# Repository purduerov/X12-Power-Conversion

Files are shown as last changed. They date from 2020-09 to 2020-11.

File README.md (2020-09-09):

# Readme for X12-Power-Conversion

Whenever you make a new part, download the datasheet and save it here _**and**_ with the part in the parts library

Always pull other people's changes before beginning to work
`git pull`

Be sure to push your changes after  working on them. Run:
1. `git add .` to add any files in this directory or a subdirectory
or `git add -u` to add any modified files
2. (Optional) `git clean -nX` to see what ignored files can be removed
	`git clean -fX` removes ignored files (Eagle backups)
3. `git commit -m "helpful commit message"` with a description of the work that you did
4. `git push` to push your work to github

Other helpful commands
* `git status` says information about modified and staged files
* `git log` shows the recent commits of the repository
* `git log filename.extension` show the recent commits for just that file
* `git checkout first-couple-letter-of-commit-id` lets you go back to a previous version
* `git checkout master` brings you back to the latest commit
* `git tag` lists the tags
* `git tag -a orderX -m "the version of the board placed for the X'th order"` tag a specific commit
* `git push --tags` needed to push tags to remote
* `git show orderX` show the commit log for the given tag
* `git checkout orderX` go back and interact with the files at the tagged commit

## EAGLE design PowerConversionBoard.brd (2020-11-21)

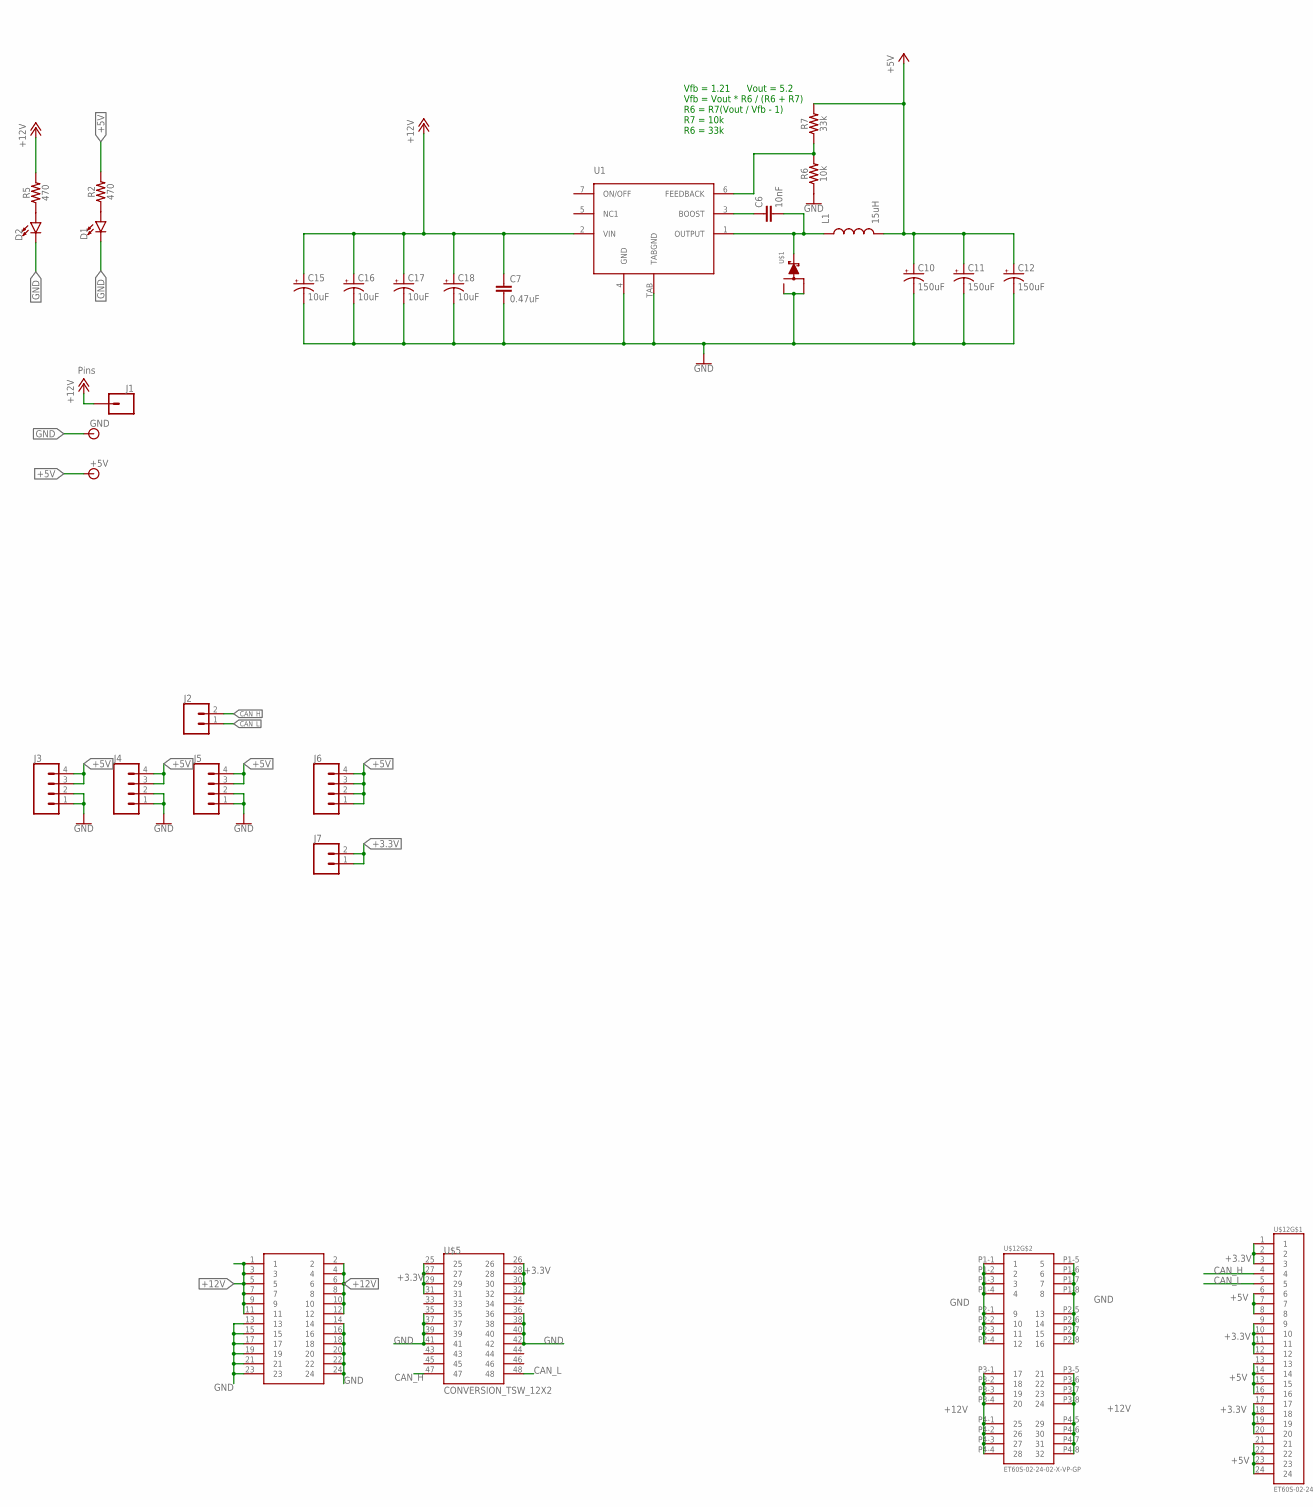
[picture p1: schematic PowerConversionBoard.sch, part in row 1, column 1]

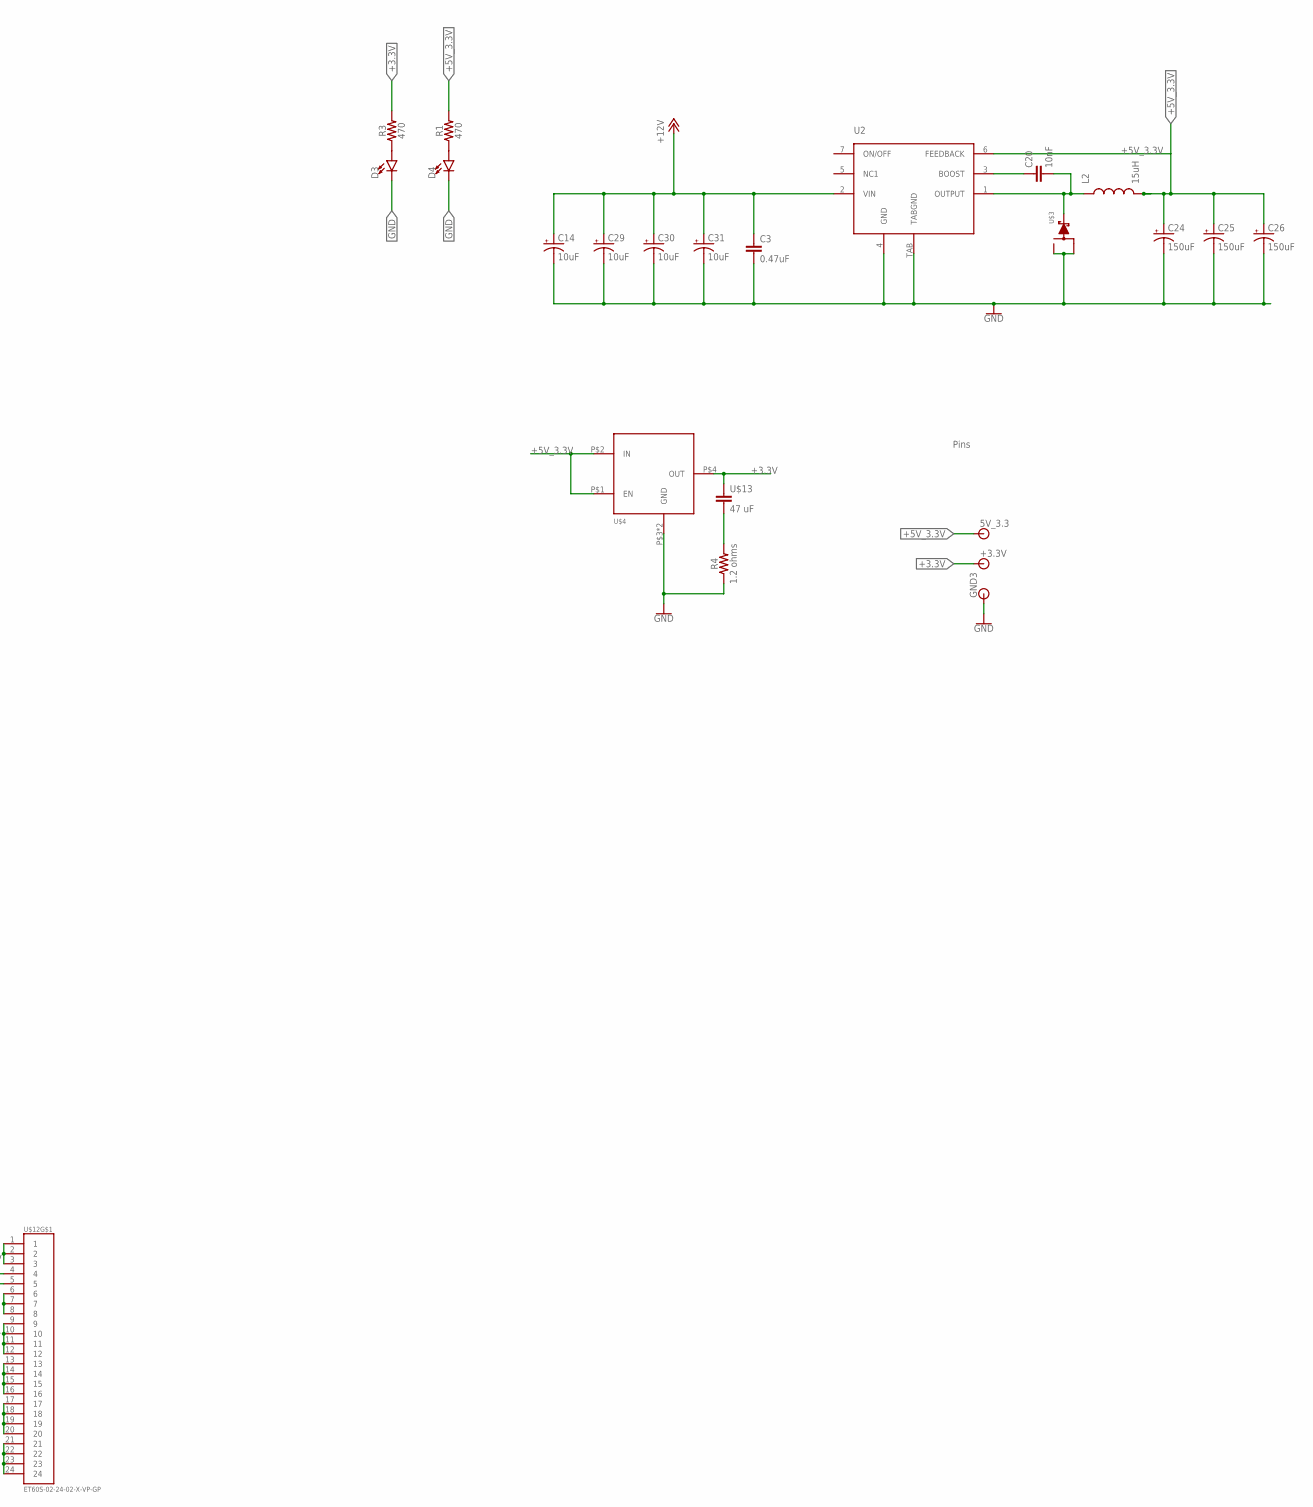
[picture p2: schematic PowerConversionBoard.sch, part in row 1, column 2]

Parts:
5V_3.3: BANANA_CONN
+3.3V, +5V: BANANA_CONN
C3, C7: 0.47uF; C0603
C6, C20: 10nF; 0603
C10, C11, C12, C24, C25, C26: 150uF; CTAN(7.30_4.30MM)
C14, C15, C16, C17, C18, C29, C30, C31: 10uF; CTAN(7.30_4.30MM)
D1, D2, D3, D4: LED0603; LED-0603
GND, GND3: BANANA_CONN
J1: CONN_01; 1X01
J2, J7: CONN_02; 1X02
J3, J4, J5, J6: CONN_04; 1X04
L1, L2: 15uH; HCMA1305
R1, R2, R3, R5: 470; 0603
R4: 1.2 ohms; 0603
R6: 10k; 0603
R7: 33k; 0603
U1, U2: LM2678
U$1, U$3: SWITCHMODE_SCHOTTKY; DPAK-3
U$4: TO-263
U$5: CONVERSION_TSW_12X2
U$12: ET60S-02-24-02-X-VP-GP
U$13: 47 uF; RESC0603_N

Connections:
+3.3V: +3.3V.P$1, J7.1, J7.2, R3.2, U$4.P$4 (OUT), U$5.25, U$5.26, U$5.27, U$5.28, U$5.29, U$5.30, U$5.31, U$5.32, U$12.1, U$12.2, U$12.3, U$12.9, U$12.10, U$12.11, U$12.12, U$12.17, U$12.18, U$12.19, U$12.20, U$13.1
+5V: +5V.P$1, C10.+, C11.+, C12.+, J3.3, J3.4, J4.3, J4.4, J5.3, J5.4, J6.1, J6.2, J6.3, J6.4, L1.2, R2.2, R7.2, U$12.6, U$12.7, U$12.8, U$12.13, U$12.14, U$12.15, U$12.16, U$12.21, U$12.22, U$12.23, U$12.24
+5V_3.3V: 5V_3.3.P$1, C24.+, C25.+, C26.+, L2.2, R1.2, U2.6 (FEEDBACK), U$4.P$1 (EN), U$4.P$2 (IN)
+12V: C3.1, C7.1, C14.+, C15.+, C16.+, C17.+, C18.+, C29.+, C30.+, C31.+, J1.1, R5.2, U1.2 (VIN), U2.2 (VIN), U$5.1, U$5.2, U$5.3, U$5.4, U$5.5, U$5.6, U$5.7, U$5.8, U$5.9, U$5.10, U$5.11, U$5.12, U$12.P3-1 (17), U$12.P3-2 (18), U$12.P3-3 (19), U$12.P3-4 (20), U$12.P3-5 (21), U$12.P3-6 (22), U$12.P3-7 (23), U$12.P3-8 (24), U$12.P4-1 (25), U$12.P4-2 (26), U$12.P4-3 (27), U$12.P4-4 (28), U$12.P4-5 (29), U$12.P4-6 (30), U$12.P4-7 (31), U$12.P4-8 (32)
BST: C6.1, U1.3 (BOOST)
BST_5_3: C20.1, U2.3 (BOOST)
CAN_H: J2.2, U$5.47, U$12.4
CAN_L: J2.1, U$5.48, U$12.5
FB: R6.2, R7.1, U1.6 (FEEDBACK)
GND: C3.2, C7.2, C10.-, C11.-, C12.-, C14.-, C15.-, C16.-, C17.-, C18.-, C24.-, C25.-, C26.-, C29.-, C30.-, C31.-, D1.C, D2.C, D3.C, D4.C, GND.P$1, GND3.P$1, J3.1, J3.2, J4.1, J4.2, J5.1, J5.2, R4.1, R6.1, U1.4 (GND), U1.TAB (TABGND), U2.4 (GND), U2.TAB (TABGND), U$1.P$1, U$1.P$3, U$3.P$1, U$3.P$3, U$4.P$3 (GND), U$4.P$6 (GND), U$5.13, U$5.14, U$5.15, U$5.16, U$5.17, U$5.18, U$5.19, U$5.20, U$5.21, U$5.22, U$5.23, U$5.24, U$5.35, U$5.36, U$5.37, U$5.38, U$5.39, U$5.40, U$5.41, U$5.42, U$12.P1-1 (1), U$12.P1-2 (2), U$12.P1-3 (3), U$12.P1-4 (4), U$12.P1-5 (5), U$12.P1-6 (6), U$12.P1-7 (7), U$12.P1-8 (8), U$12.P2-1 (9), U$12.P2-2 (10), U$12.P2-3 (11), U$12.P2-4 (12), U$12.P2-5 (13), U$12.P2-6 (14), U$12.P2-7 (15), U$12.P2-8 (16)
unnamed: D2.A, R5.1
unnamed: D3.A, R3.1
unnamed: D4.A, R1.1
unnamed: D1.A, R2.1
unnamed: R4.2, U$13.2
SW_5: C6.2, L1.1, U1.1 (OUTPUT), U$1.P$4
SW_5_3: C20.2, L2.1, U2.1 (OUTPUT), U$3.P$4

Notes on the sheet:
Pins
Vfb = 1.21 Vout = 5.2 Vfb = Vout * R6 / (R6 + R7) R6 = R7(Vout / Vfb - 1) R7 = 10k R6 = 33k

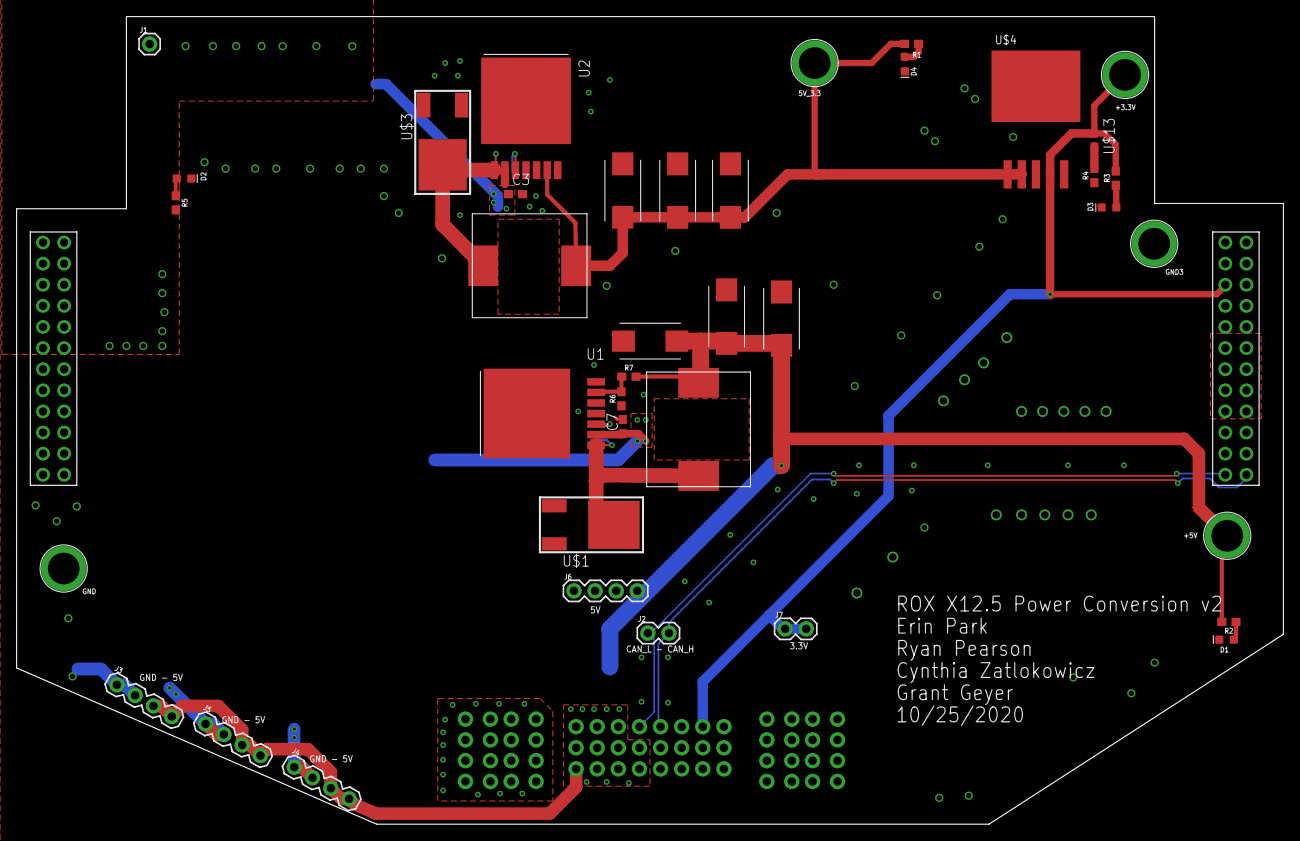
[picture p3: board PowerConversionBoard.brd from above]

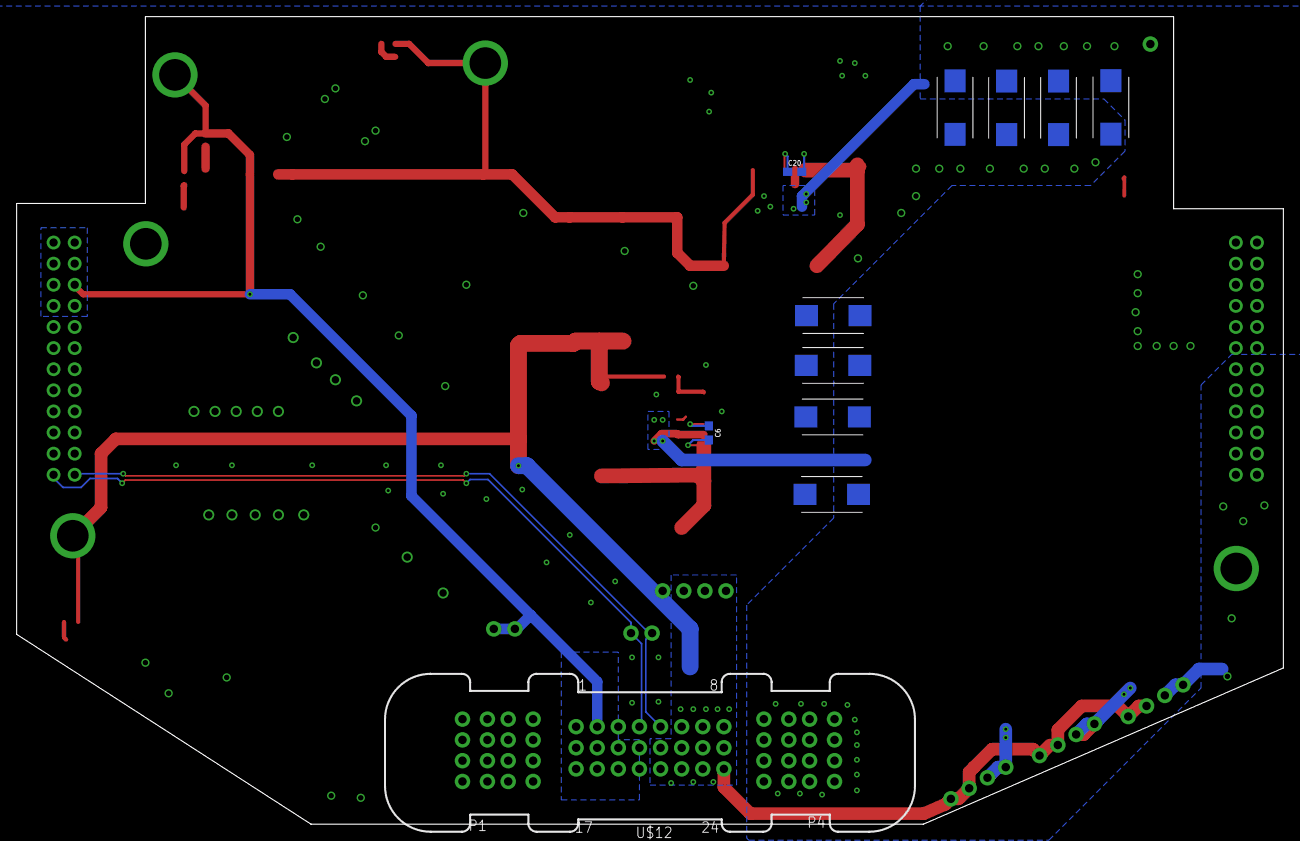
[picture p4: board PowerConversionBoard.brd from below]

Board: 2 copper layers, 152.4 x 97.2 mm, 51 parts (11 on the bottom side), 17 nets.

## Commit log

2019-09-25 created schematic
    [PowerConversionBoard.sch]
2019-09-28 preliminary crap
    [PowerConversionBoard.sch]
2019-09-28 fixing local copy
    [PowerConversionBoard.sch]
2019-09-28 Grid size changed to 0.01 in - same as last years
    [PowerConversionBoard.sch]
2019-09-28 saving changes
    [PowerConversionBoard.sch]
2019-10-02 Good Inductor
    [PowerConversionBoard.sch]
2019-10-09 Added LEDs to schematic
    [PowerConversionBoard.sch]
2019-10-09 Put in good LEDs
    [PowerConversionBoard.sch]
2019-10-16 Powerpoint
    test
2019-10-19 Added board, removed powerpoint
    [PowerConversionBoard.brd]
2019-10-19 Added LED and test points
    [PowerConversionBoard.sch]
2019-10-23 board work
    [PowerConversionBoard.sch]
2019-10-26 worked on board
    [PowerConversionBoard.brd, PowerConversionBoard.sch]
2019-11-02 updated board
    [PowerConversionBoard.brd, PowerConversionBoard.sch]
2019-11-04 Did some stuff
    [PowerConversionBoard.brd, PowerConversionBoard.sch]
2019-11-05 added connector for backplane
    [PowerConversionBoard.brd, PowerConversionBoard.sch]
2019-11-07 power plane
    [PowerConversionBoard.brd, PowerConversionBoard.sch]
2019-11-07 plane ez
    [PowerConversionBoard.brd]
2019-11-07 ez fix
    [PowerConversionBoard.brd, PowerConversionBoard.sch]
2019-11-08 good progress
    [PowerConversionBoard.brd, PowerConversionBoard.sch]
2019-11-09 Final touch
    [PowerConversionBoard.brd]
2019-11-10 fixed the forward/backward annotation error
    [PowerConversionBoard.brd, PowerConversionBoard.sch]
2019-11-11 fixed weird
    [PowerConversionBoard.brd]
2019-11-13 Board presentation file
    [PowerConversionBoard.brd]
2019-11-15 Added ground planes
2019-11-16 Plane Updates
    [PowerConversionBoard.brd]
2019-11-17 bunch of plane things and fixing weird shapes
    [PowerConversionBoard.brd]
2019-11-18 plane stuff, 12v op now
2019-11-24 Moved the gnd pin and tp
    [PowerConversionBoard.brd]
2019-12-21 Final review session work
    Made 12v bigger
    fixed all remaining drc stubs etc
    some polygon changes
    Remaining work: Make the names for the volt test points bigger
    find a picture to put on there
    [PowerConversionBoard.brd]
2020-01-01 added bandana cat
    [PowerConversionBoard.brd]
2020-09-09 CAD for connectors
    [PowerConversionBoard.brd, PowerConversionBoard.sch]
2020-09-12 New stuff to do:
    smaller linear regulator for 3.3v
    make board smaller according to size given later
    [PowerConversionBoard.brd]
2020-10-23 chopped off corners
    [PowerConversionBoard.brd, PowerConversionBoard.sch]
2020-10-26 stupid outline. extra breakouts. tighter layout.
    [PowerConversionBoard.brd, PowerConversionBoard.sch]
2020-11-04 fix bad merge
    [PowerConversionBoard.brd]
2020-11-21 added resistors for adjustable and re aligned schematic
    [PowerConversionBoard.brd, PowerConversionBoard.sch]

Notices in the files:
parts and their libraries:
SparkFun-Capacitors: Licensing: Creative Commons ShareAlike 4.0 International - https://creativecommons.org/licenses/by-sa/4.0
